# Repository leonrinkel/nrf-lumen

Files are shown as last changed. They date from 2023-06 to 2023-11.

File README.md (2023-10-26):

# nrf-lumen

nRF52840 NeoPixel controller board

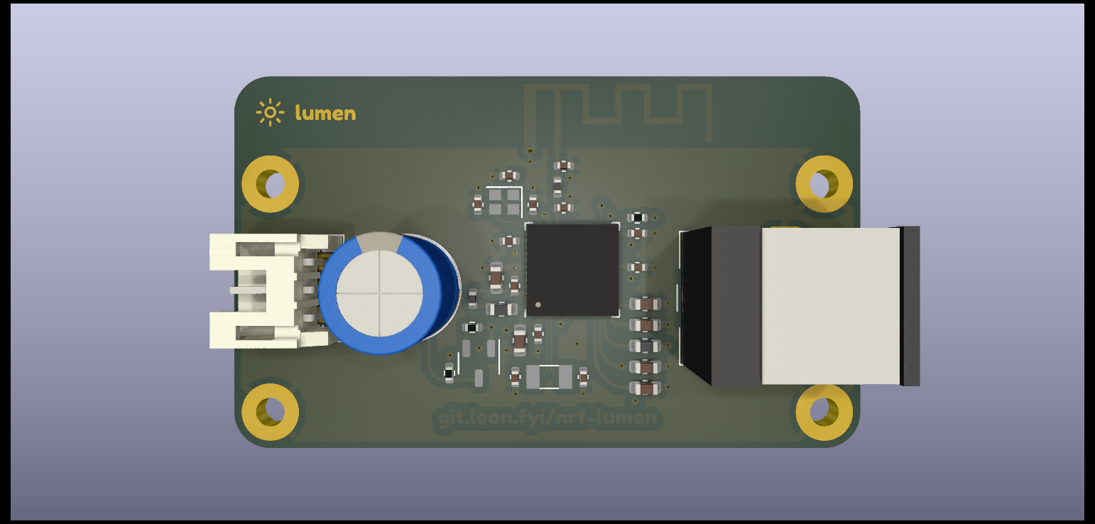
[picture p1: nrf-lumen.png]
Render of the controller board


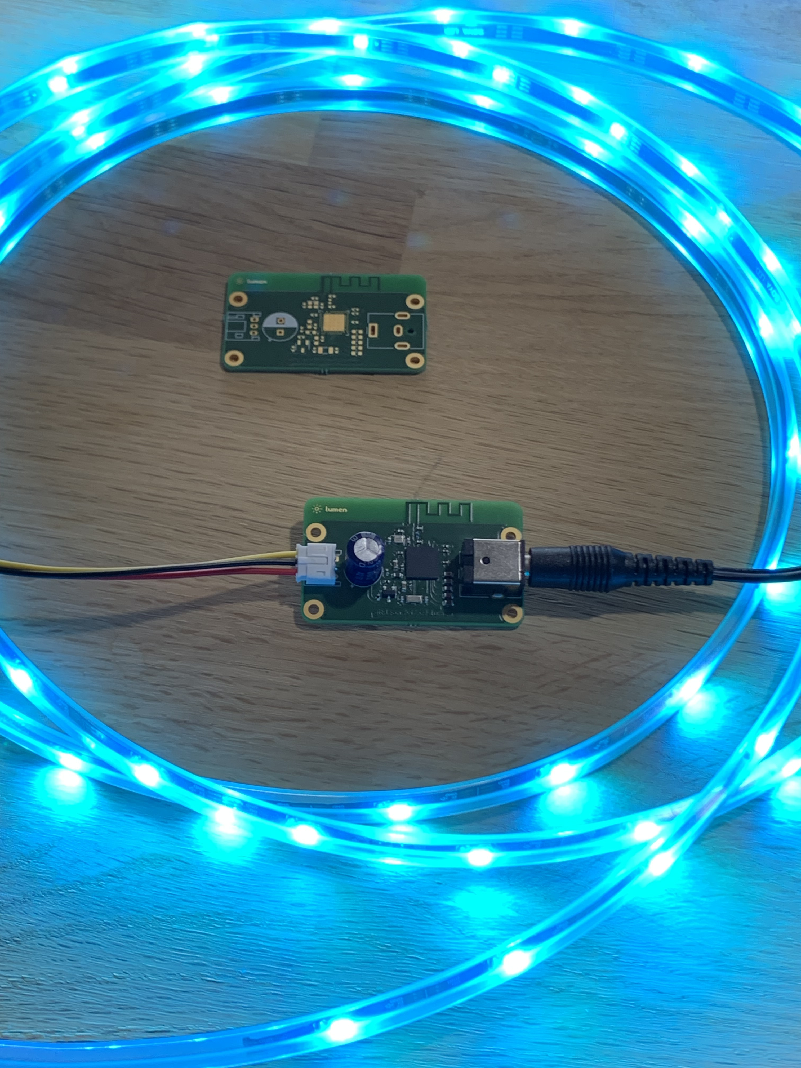
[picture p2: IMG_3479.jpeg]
Photo of the board with LED strip attached


## Initialization

> [!IMPORTANT]
> Make sure you have a proper Zephyr development environment according to the
> official documentation.

```sh
west init -m https://git.leon.fyi/lumen-sdk --mr main lumen-workspace # or
west init -m https://github.com/leonrinkel/lumen-sdk --mr main lumen-workspace
cd lumen-workspace
west update
```

## Building

```sh
west build -b lumen lumen-sdk/app # or
west build -b lumen lumen-sdk/app -- -DOVERLAY_CONFIG=debug.conf
```

## Flashing

```sh
west flash --runner jlink # or
west flash --runner pyocd
```

## Over-The-Air Update

Building automatically produces an `app_update.bin` file in the `build/zephyr`
directory. This file can be used to update firmware using the
[nRF Connect Device Manager][1].

## License

Please see [hardware/LICENSE](hardware/LICENSE) and [lumen-sdk][2]. The software
side of this project is based on [Zephyr][3] which is mostly licensed under the
[Apache-2.0][4] license.

[1]: https://www.nordicsemi.com/Products/Development-tools/nrf-connect-device-manager
[2]: https://git.leon.fyi/lumen-sdk
[3]: https://www.zephyrproject.org
[4]: http://www.apache.org/licenses/LICENSE-2.0

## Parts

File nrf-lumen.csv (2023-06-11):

Source: | /Users/leonrinkel/Desktop/nrf-lumen/nrf-lumen.kicad_sch
Date: | 2023 June 11, Sunday 20:35:35
Tool: | Eeschema (6.0.10-0)
Generator: | /Applications/KiCad/KiCad.app/Contents/SharedSupport/plugins/bom_csv_grouped_by_value.py
Component Count: | 34
Individual Components:
Item | Qty | Reference(s) | Value | LibPart | Footprint | Datasheet | Mfr. | Mfr. No | Mouser No
 |  | C1 | 12pF | Device:C | Capacitor_SMD:C_0402_1005Metric | ~ | Murata Electronics | GRM1555C1H120FA01J | 81-GRM1555C1H120FA1J
 |  | C2 | 12pF | Device:C | Capacitor_SMD:C_0402_1005Metric | ~ | Murata Electronics | GRM1555C1H120FA01J | 81-GRM1555C1H120FA1J
 |  | C3 | 0.5pF | Device:C | Capacitor_SMD:C_0402_1005Metric | ~ | Murata Electronics | GJM1555C1HR50RB12D | 81-GJM1555C1HR50RB2D
 |  | C4 | 1000µF | Device:C_Polarized | Capacitor_THT:CP_Radial_D8.0mm_P3.50mm | ~ | KEMET | ESK108M6R3AG3AA | 80-ESK108M6R3AG3AA
 |  | C5 | 0.8pF | Device:C | Capacitor_SMD:C_0402_1005Metric | ~ | Murata Electronics | GJM1555C1HR80WB01D | 81-GJM1555C1HR80WB1D
 |  | C6 | 9pF | Device:C | Capacitor_SMD:C_0402_1005Metric | ~ | Murata Electronics | GJM1555C1H9R0CB01J | 81-GJM1555C1H9R0CB1J
 |  | C7 | 9pF | Device:C | Capacitor_SMD:C_0402_1005Metric | ~ | Murata Electronics | GJM1555C1H9R0CB01J | 81-GJM1555C1H9R0CB1J
 |  | C8 | 4.7µF | Device:C | Capacitor_SMD:C_0603_1608Metric | ~ | Murata Electronics | GRT188C71C475KE13D | 81-GRT188C71C475KE13
 |  | C9 | 4.7µF | Device:C | Capacitor_SMD:C_0603_1608Metric | ~ | Murata Electronics | GRT188C71C475KE13D | 81-GRT188C71C475KE13
 |  | C10 | 4.7µF | Device:C | Capacitor_SMD:C_0603_1608Metric | ~ | Murata Electronics | GRT188C71C475KE13D | 81-GRT188C71C475KE13
 |  | C11 | 1µF | Device:C | Capacitor_SMD:C_0603_1608Metric | ~ | Murata Electronics | GRT188R61H105KE13D | 81-GRT188R61H105KE3D
 |  | C12 | 1µF | Device:C | Capacitor_SMD:C_0603_1608Metric | ~ | Murata Electronics | GRT188R61H105KE13D | 81-GRT188R61H105KE3D
 |  | C13 | 4.7µF | Device:C | Capacitor_SMD:C_0603_1608Metric | ~ | Murata Electronics | GRT188C71C475KE13D | 81-GRT188C71C475KE13
 |  | C14 | 100nF | Device:C | Capacitor_SMD:C_0402_1005Metric | ~ | Murata Electronics | GRM155R71A104KA01D | 81-GRM155R71A104KA1D
 |  | C15 | 47nF | Device:C | Capacitor_SMD:C_0402_1005Metric | ~ | Murata Electronics | GRM155C71H473JE19D | 81-GRM155C71H473JE9D
 |  | C16 | 100nF | Device:C | Capacitor_SMD:C_0402_1005Metric | ~ | Murata Electronics | GRM155R71A104KA01D | 81-GRM155R71A104KA1D
 |  | C17 | 100nF | Device:C | Capacitor_SMD:C_0402_1005Metric | ~ | Murata Electronics | GRM155R71A104KA01D | 81-GRM155R71A104KA1D
 |  | C18 | 100pF | Device:C | Capacitor_SMD:C_0402_1005Metric | ~ | Murata Electronics | GRM1555C1H101JA01D | 81-GRM1555C1H101JA1D
 |  | C19 | 100nF | Device:C | Capacitor_SMD:C_0402_1005Metric | ~ | Murata Electronics | GRM155R71A104KA01D | 81-GRM155R71A104KA1D
 |  | J1 | Barrel_Jack_MountingPin | Connector:Barrel_Jack_MountingPin | Connector_BarrelJack:BarrelJack_CUI_PJ-063AH_Horizontal | ./datasheets/pj-063ah.pdf | CUI Devices | PJ-063AH | 490-PJ-063AH
 |  | J2 | Conn_01x03 | Connector_Generic:Conn_01x03 | Connector_JST:JST_PH_S3B-PH-K_1x03_P2.00mm_Horizontal | ~ | SparkFun | PRT-09750 | 474-PRT-09750
 |  | L1 | 4.7nH | Device:L | Inductor_SMD:L_0402_1005Metric | ~ | Murata Electronics | LQW15AN4N7B00D | 81-LQW15AN4N7B00D
 |  | L2 | 10µH | Device:L | Inductor_SMD:L_0603_1608Metric | ~ | Murata Electronics | LQM18DZ100M70L | 81-LQM18DZ100M70L
 |  | L3 | 10µH | Device:L | Inductor_SMD:L_0603_1608Metric | ~ | Murata Electronics | LQM18DZ100M70L | 81-LQM18DZ100M70L
 |  | L4 | 15nH | Device:L | Inductor_SMD:L_0402_1005Metric | ~ | Murata Electronics | LQG15HS15NG02D | 81-LQG15HS15NG02D
 |  | Q1 | BSS138 | Transistor_FET:BSS138 | Package_TO_SOT_SMD:SOT-23-3 | https://www.onsemi.com/pub/Collateral/BSS138-D.PDF | Diodes Incorporated | BSS138-7-F | 621-BSS138-7-F
 |  | R1 | 10kΩ | Device:R | Resistor_SMD:R_0402_1005Metric | ~ | YAGEO | RC0402FR-0710KL | 603-RC0402FR-0710KL
 |  | R2 | 10kΩ | Device:R | Resistor_SMD:R_0402_1005Metric | ~ | YAGEO | RC0402FR-0710KL | 603-RC0402FR-0710KL
 |  | R3 | 10kΩ | Device:R | Resistor_SMD:R_0402_1005Metric | ~ | YAGEO | RC0402FR-0710KL | 603-RC0402FR-0710KL
 |  | TP1 | TestPoint | Connector:TestPoint | TestPoint:TestPoint_Pad_D1.0mm | ~
 |  | TP2 | TestPoint | Connector:TestPoint | TestPoint:TestPoint_Pad_D1.0mm | ~
 |  | U1 | nRF52840 | MCU_Nordic:nRF52840 | Package_DFN_QFN:Nordic_AQFN-73-1EP_7x7mm_P0.5mm | http://infocenter.nordicsemi.com/topic/com.nordic.infocenter.nrf52/dita/nrf52/chips/nrf52840.html | Nordic Semiconductor | NRF52840-QIAA-R7 | 949-NRF52840-QIAA-R7
 |  | Y1 | 32MHz | Device:Crystal_GND24 | Crystal:Crystal_SMD_2016-4Pin_2.0x1.6mm | ~ | ABRACON | ABM11W-32.0000MHZ-8-D1X-T3 | 815-11W32-8D1XT
 |  | Y2 | 32.768kHz | Device:Crystal | Crystal:Crystal_SMD_3215-2Pin_3.2x1.5mm | ~ | ABRACON | ABS07-32.768KHZ-7-T | 815-ABS07-32.768K7T
Collated Components:
Item | Qty | Reference(s) | Value | LibPart | Footprint | Datasheet | Mfr. | Mfr. No | Mouser No
1 | 2 | C1, C2 | 12pF | Device:C | Capacitor_SMD:C_0402_1005Metric | ~ | Murata Electronics | GRM1555C1H120FA01J | 81-GRM1555C1H120FA1J
2 | 1 | C3 | 0.5pF | Device:C | Capacitor_SMD:C_0402_1005Metric | ~ | Murata Electronics | GJM1555C1HR50RB12D | 81-GJM1555C1HR50RB2D
3 | 1 | C4 | 1000µF | Device:C_Polarized | Capacitor_THT:CP_Radial_D8.0mm_P3.50mm | ~ | KEMET | ESK108M6R3AG3AA | 80-ESK108M6R3AG3AA
4 | 1 | C5 | 0.8pF | Device:C | Capacitor_SMD:C_0402_1005Metric | ~ | Murata Electronics | GJM1555C1HR80WB01D | 81-GJM1555C1HR80WB1D
5 | 2 | C6, C7 | 9pF | Device:C | Capacitor_SMD:C_0402_1005Metric | ~ | Murata Electronics | GJM1555C1H9R0CB01J | 81-GJM1555C1H9R0CB1J
6 | 4 | C8, C9, C10, C13 | 4.7µF | Device:C | Capacitor_SMD:C_0603_1608Metric | ~ | Murata Electronics | GRT188C71C475KE13D | 81-GRT188C71C475KE13
7 | 2 | C11, C12 | 1µF | Device:C | Capacitor_SMD:C_0603_1608Metric | ~ | Murata Electronics | GRT188R61H105KE13D | 81-GRT188R61H105KE3D
8 | 4 | C14, C16, C17, C19 | 100nF | Device:C | Capacitor_SMD:C_0402_1005Metric | ~ | Murata Electronics | GRM155R71A104KA01D | 81-GRM155R71A104KA1D
9 | 1 | C15 | 47nF | Device:C | Capacitor_SMD:C_0402_1005Metric | ~ | Murata Electronics | GRM155C71H473JE19D | 81-GRM155C71H473JE9D
10 | 1 | C18 | 100pF | Device:C | Capacitor_SMD:C_0402_1005Metric | ~ | Murata Electronics | GRM1555C1H101JA01D | 81-GRM1555C1H101JA1D
11 | 1 | J1 | Barrel_Jack_MountingPin | Connector:Barrel_Jack_MountingPin | Connector_BarrelJack:BarrelJack_CUI_PJ-063AH_Horizontal | ./datasheets/pj-063ah.pdf | CUI Devices | PJ-063AH | 490-PJ-063AH
12 | 1 | J2 | Conn_01x03 | Connector_Generic:Conn_01x03 | Connector_JST:JST_PH_S3B-PH-K_1x03_P2.00mm_Horizontal | ~ | SparkFun | PRT-09750 | 474-PRT-09750
13 | 1 | L1 | 4.7nH | Device:L | Inductor_SMD:L_0402_1005Metric | ~ | Murata Electronics | LQW15AN4N7B00D | 81-LQW15AN4N7B00D
14 | 2 | L2, L3 | 10µH | Device:L | Inductor_SMD:L_0603_1608Metric | ~ | Murata Electronics | LQM18DZ100M70L | 81-LQM18DZ100M70L
15 | 1 | L4 | 15nH | Device:L | Inductor_SMD:L_0402_1005Metric | ~ | Murata Electronics | LQG15HS15NG02D | 81-LQG15HS15NG02D
16 | 1 | Q1 | BSS138 | Transistor_FET:BSS138 | Package_TO_SOT_SMD:SOT-23-3 | https://www.onsemi.com/pub/Collateral/BSS138-D.PDF | Diodes Incorporated | BSS138-7-F | 621-BSS138-7-F
17 | 3 | R1, R2, R3 | 10kΩ | Device:R | Resistor_SMD:R_0402_1005Metric | ~ | YAGEO | RC0402FR-0710KL | 603-RC0402FR-0710KL
18 | 2 | TP1, TP2 | TestPoint | Connector:TestPoint | TestPoint:TestPoint_Pad_D1.0mm | ~
19 | 1 | U1 | nRF52840 | MCU_Nordic:nRF52840 | Package_DFN_QFN:Nordic_AQFN-73-1EP_7x7mm_P0.5mm | http://infocenter.nordicsemi.com/topic/com.nordic.infocenter.nrf52/dita/nrf52/chips/nrf52840.html | Nordic Semiconductor | NRF52840-QIAA-R7 | 949-NRF52840-QIAA-R7
20 | 1 | Y1 | 32MHz | Device:Crystal_GND24 | Crystal:Crystal_SMD_2016-4Pin_2.0x1.6mm | ~ | ABRACON | ABM11W-32.0000MHZ-8-D1X-T3 | 815-11W32-8D1XT
21 | 1 | Y2 | 32.768kHz | Device:Crystal | Crystal:Crystal_SMD_3215-2Pin_3.2x1.5mm | ~ | ABRACON | ABS07-32.768KHZ-7-T | 815-ABS07-32.768K7T

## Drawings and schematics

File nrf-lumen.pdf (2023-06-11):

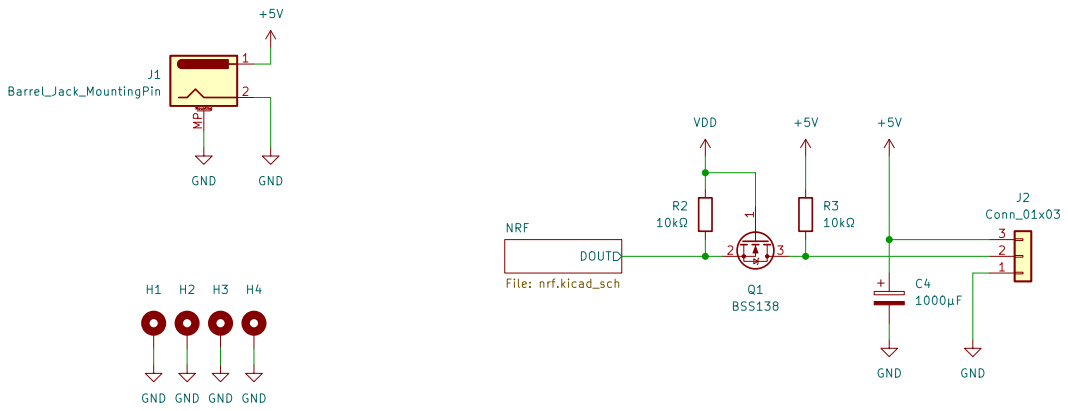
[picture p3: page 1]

git.leon.fyi/nrf-lumen DOUT NRF

leon@rinkel.me
File: nrf-lumen.kicad_sch Sheet: / Leon Rinkel

Id: 1/2 Title: nrf-lumen

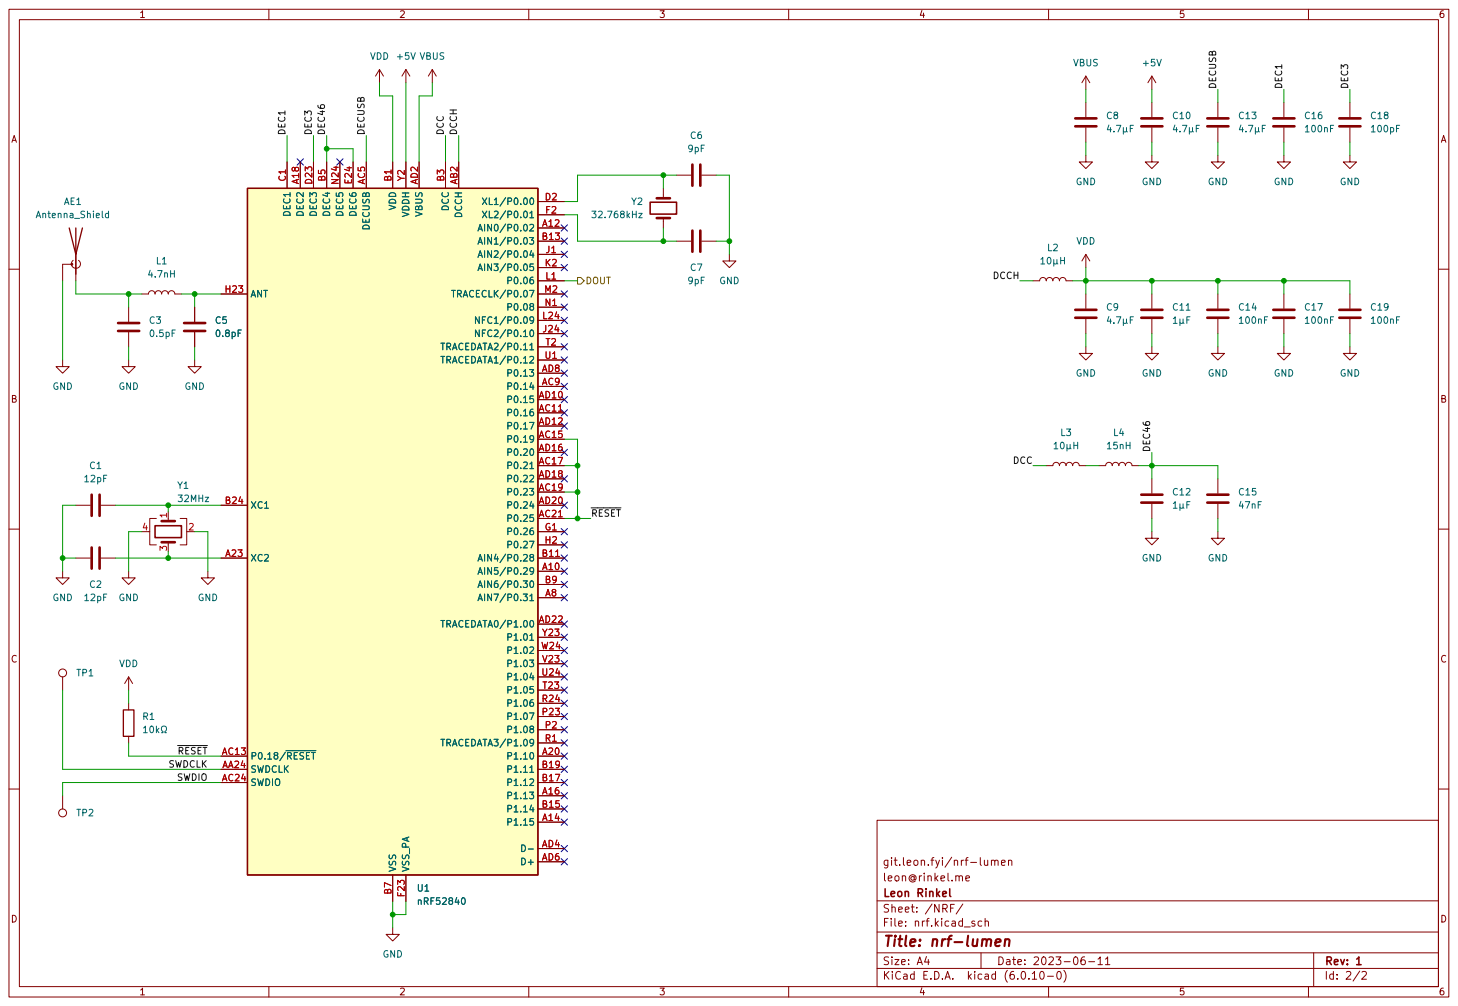
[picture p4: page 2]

leon@rinkel.me
File: nrf.kicad_sch Sheet: /NRF/ Leon Rinkel

Id: 2/2 Title: nrf-lumen

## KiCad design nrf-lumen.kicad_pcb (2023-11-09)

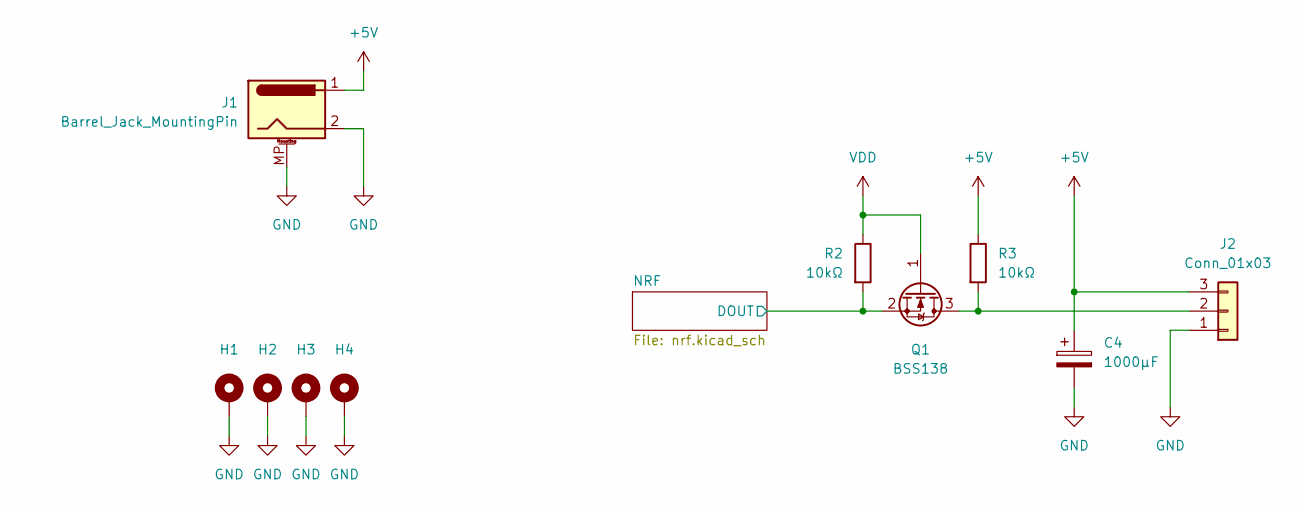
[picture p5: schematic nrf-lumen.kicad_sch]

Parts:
C4: 1000µF; CP_Radial_D8.0mm_P3.50mm; MPN ESK108M6R3AG3AA
H1, H2, H3, H4: MountingHole_Pad; MountingHole_2.2mm_M2_Pad
J1: Barrel_Jack_MountingPin; BarrelJack_CUI_PJ-063AH_Horizontal; MPN PJ-063AH
J2: Conn_01x03; JST_PH_S3B-PH-K_1x03_P2.00mm_Horizontal; MPN PRT-09750
Q1: BSS138; SOT-23-3; MPN BSS138-7-F
R2, R3: 10kΩ; R_0402_1005Metric; MPN RC0402FR-0710KL

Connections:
+5V: C4.1, J1.1, J2.3, R3.1; also elsewhere on the board
/NRF/DOUT: Q1.2 (S), R2.2; also elsewhere on the board
GND: C4.2, H1.1, H2.1, H3.1, H4.1, J1.2, J1.MP (MountPin), J2.1; also elsewhere on the board
unnamed: J2.2, Q1.3 (D), R3.2
VDD: Q1.1 (G), R2.1; also elsewhere on the board

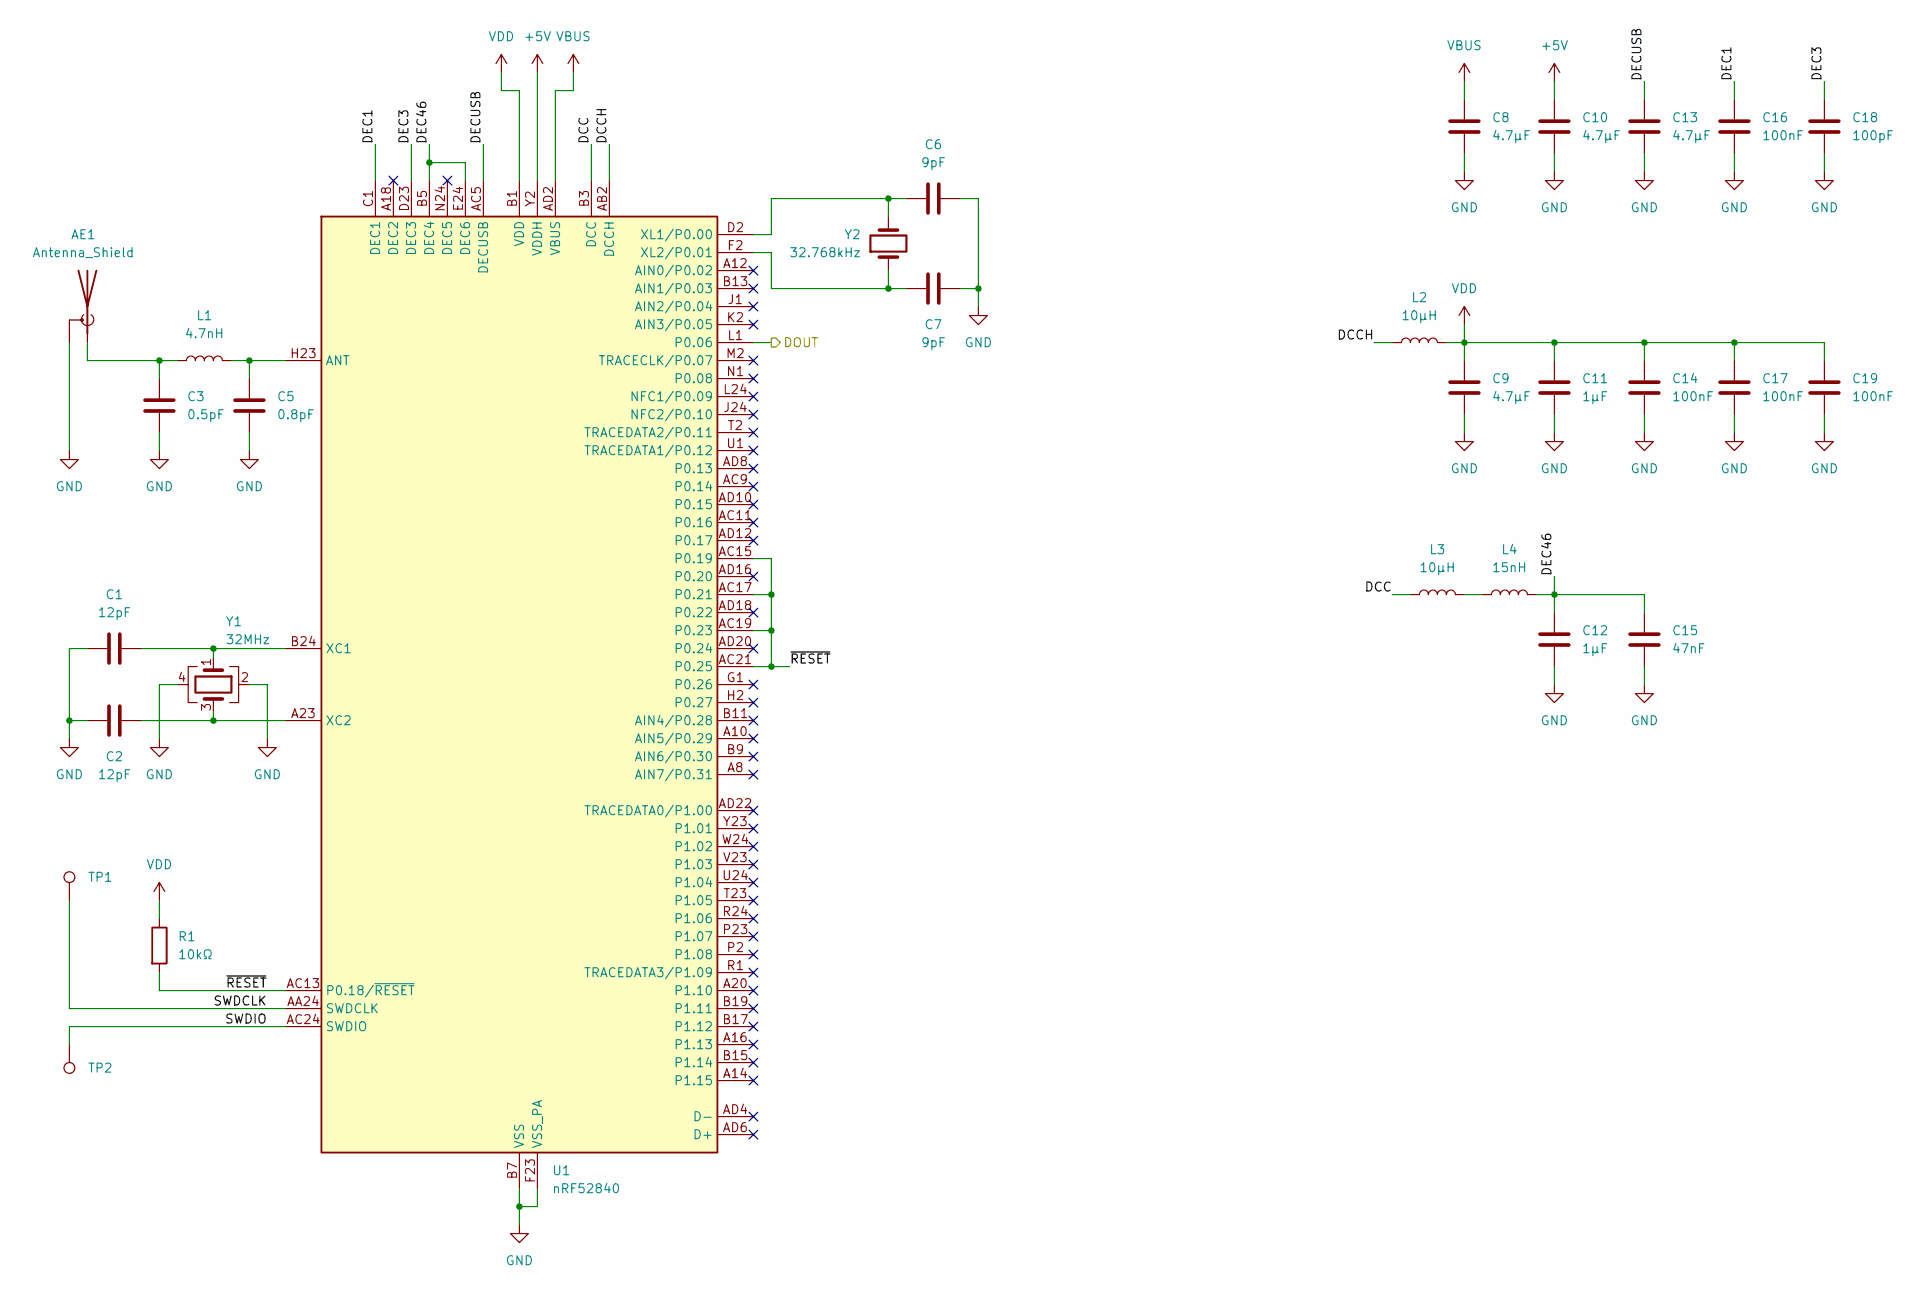
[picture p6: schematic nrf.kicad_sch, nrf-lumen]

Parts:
AE1: Antenna_Shield; Texas_SWRA117D_2.4GHz_Right
C1, C2: 12pF; C_0402_1005Metric; MPN GRM1555C1H120FA01J
C3: 0.5pF; C_0402_1005Metric; MPN GJM1555C1HR50RB12D
C5: 0.8pF; C_0402_1005Metric; MPN GJM1555C1HR80WB01D
C6, C7: 9pF; C_0402_1005Metric; MPN GJM1555C1H9R0CB01J
C8, C9, C10, C13: 4.7µF; C_0603_1608Metric; MPN GRT188C71C475KE13D
C11, C12: 1µF; C_0603_1608Metric; MPN GRT188R61H105KE13D
C14, C16, C17, C19: 100nF; C_0402_1005Metric; MPN GRM155R71A104KA01D
C15: 47nF; C_0402_1005Metric; MPN GRM155C71H473JE19D
C18: 100pF; C_0402_1005Metric; MPN GRM1555C1H101JA01D
L1: 4.7nH; L_0402_1005Metric; MPN LQW15AN4N7B00D
L2, L3: 10µH; L_0603_1608Metric; MPN LQM18DZ100M70L
L4: 15nH; L_0402_1005Metric; MPN LQG15HS15NG02D
R1: 10kΩ; R_0402_1005Metric; MPN RC0402FR-0710KL
TP1, TP2: TestPoint; TestPoint_Pad_D1.0mm
U1: nRF52840; Nordic_AQFN-73-1EP_7x7mm_P0.5mm; MPN NRF52840-QIAA-R7
Y1: 32MHz; Crystal_SMD_2016-4Pin_2.0x1.6mm; MPN ABM11W-32.0000MHZ-8-D1X-T3
Y2: 32.768kHz; Crystal_SMD_3215-2Pin_3.2x1.5mm; MPN ABS07-32.768KHZ-7-T

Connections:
+5V: C10.1, U1.Y2 (VDDH); also elsewhere on the board
/NRF/DCC: L3.1, U1.B3 (DCC)
/NRF/DCCH: L2.1, U1.AB2 (DCCH)
/NRF/DEC1: C16.1, U1.C1 (DEC1)
/NRF/DEC3: C18.1, U1.D23 (DEC3)
/NRF/DEC46: C12.1, C15.1, L4.2, U1.B5 (DEC4), U1.E24 (DEC6)
/NRF/DECUSB: C13.1, U1.AC5 (DECUSB)
/NRF/DOUT: U1.L1 (P0.06); also elsewhere on the board
/NRF/SWDCLK: TP1.1, U1.AA24 (SWDCLK)
/NRF/SWDIO: TP2.1, U1.AC24 (SWDIO)
/NRF/~RESET: R1.2, U1.AC13 (P0.18/~RESET), U1.AC15 (P0.19), U1.AC17 (P0.21), U1.AC19 (P0.23), U1.AC21 (P0.25)
GND: AE1.2 (Shield), C1.1, C2.1, C3.2, C5.2, C6.2, C7.2, C8.2, C9.2, C10.2, C11.2, C12.2, C13.2, C14.2, C15.2, C16.2, C17.2, C18.2, C19.2, U1.B7 (VSS), U1.EP (VSS), U1.F23 (VSS_PA), Y1.2, Y1.4; also elsewhere on the board
unnamed: AE1.1 (A), C3.1, L1.1
unnamed: L3.2, L4.1
unnamed: C5.1, L1.2, U1.H23 (ANT)
unnamed: C1.2, U1.B24 (XC1), Y1.1
unnamed: C2.2, U1.A23 (XC2), Y1.3
unnamed: C6.1, U1.D2 (XL1/P0.00), Y2.2
unnamed: C7.1, U1.F2 (XL2/P0.01), Y2.1
VBUS: C8.1, U1.AD2 (VBUS)
VDD: C9.1, C11.1, C14.1, C17.1, C19.1, L2.2, R1.1, U1.A22 (VDD), U1.AD14 (VDD), U1.AD23 (VDD), U1.B1 (VDD), U1.W1 (VDD); also elsewhere on the board

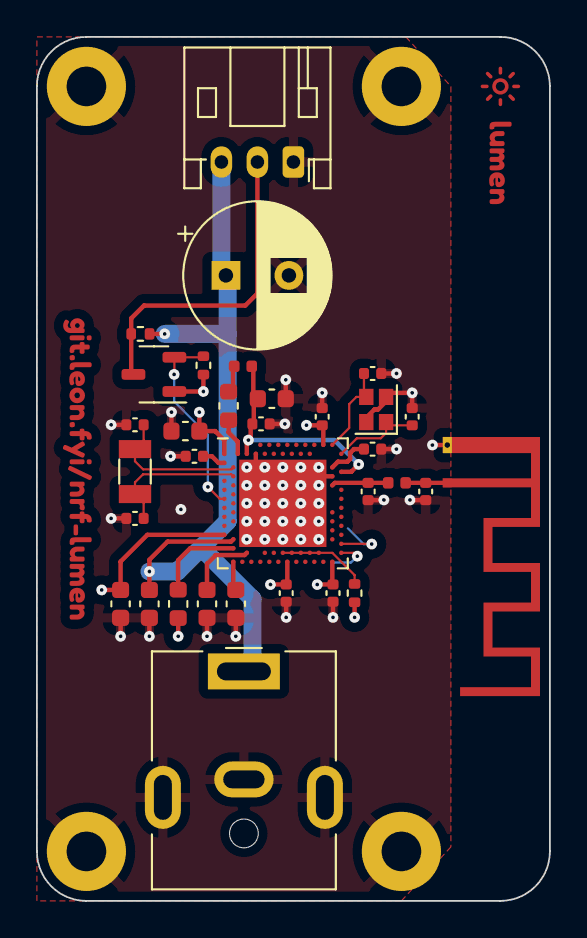
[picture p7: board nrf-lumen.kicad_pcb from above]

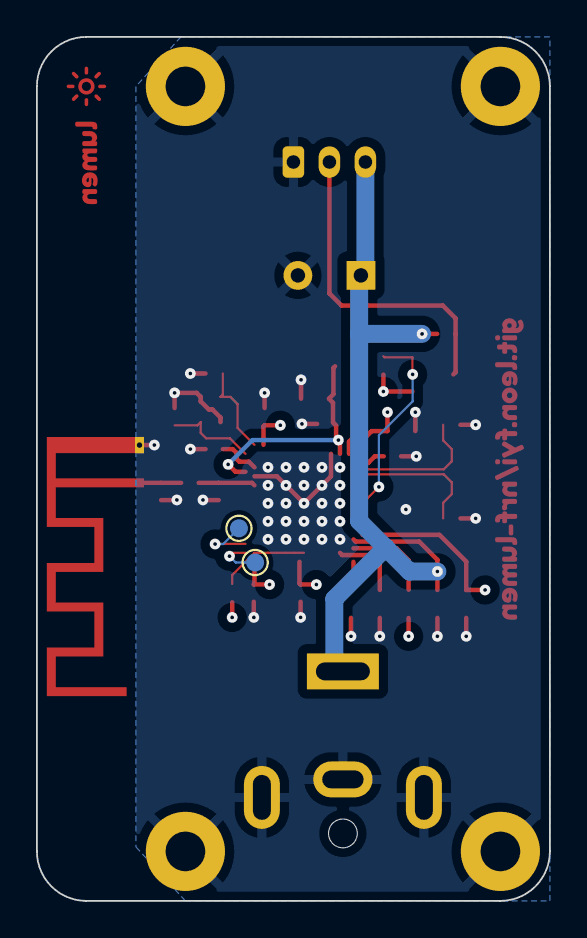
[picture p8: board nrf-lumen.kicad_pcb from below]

Board: 4 copper layers, 28.5 x 48.0 mm, 41 parts (2 on the bottom side), 22 nets.

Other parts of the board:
kibuzzard-64860F80: G***; kibuzzard-64860F80
kibuzzard-64861007: G***; kibuzzard-64861007
